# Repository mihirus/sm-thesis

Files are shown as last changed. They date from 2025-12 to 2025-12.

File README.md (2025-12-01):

```bash
├── cad
│   ├── cores
│   │   ├── etd44_core.SLDPRT
│   │   ├── etd49_core.SLDPRT
│   │   ├── etd54_core.SLDPRT
│   │   └── etd59_core.SLDPRT
│   ├── etd59_bobbin_integrated_secondary.SLDPRT
│   ├── etd59_shunt_AB.SLDPRT
│   ├── inverter_sink_v2_vertical.SLDPRT
│   └── leakage-transformer-assembly
│       ├── etd59_bobbin_integrated_v7.SLDPRT
│       ├── etd59_core.SLDPRT
│       ├── ETD59-integrated-base-raised-nov21.SLDPRT
│       ├── ETD59-integrated-bottom-raised-0.8mm-dec9.SLDPRT
│       ├── ETD59-integrated-top-raised-0.8mm-dec9.SLDPRT
│       ├── etd59-withsinks-raised-dec9.SLDASM
│       ├── secondary-placeholder.SLDPRT
│       ├── shunt-heat-sink.SLDPRT
│       └── shunt-heat-spreader.SLDPRT
├── optimization
│   ├── opt_baseline.py
│   ├── opt_heatsink.py
│   └── opt_integrated.py
├── pcb
│   ├── custom_assets (collapsed)
│   ├── inverter
│   │   ├── half_bridge.kicad_sch
│   │   ├── inverter.kicad_pcb
│   │   ├── inverter.kicad_prl
│   │   ├── inverter.kicad_pro
│   │   ├── inverter.kicad_sch
│   │   ├── inverter.pdf
│   │   ├── inverter.round-tracks-config
│   │   ├── inverter.step
│   │   └── outputs
│   │       ├── inverter-B_Cu.pdf
│   │       ├── inverter-F_Cu.pdf
│   │       ├── inverter-In1_Cu.pdf
│   │       └── inverter-In2_Cu.pdf
│   ├── multiplier-slu15mg-2p
│   │   ├── full_wave_cell-.kicad_sch
│   │   ├── full_wave_cell.kicad_sch
│   │   ├── multiplier-slu15mg.kicad_pcb
│   │   ├── multiplier-slu15mg.kicad_prl
│   │   ├── multiplier-slu15mg.kicad_pro
│   │   ├── multiplier-slu15mg.kicad_sch
│   │   ├── multiplier-slu15mg.step
│   │   └── outputs
│   │       ├── multiplier-slu15mg-B_Cu.pdf
│   │       ├── multiplier-slu15mg-Edge_Cuts.pdf
│   │       └── multiplier-slu15mg-F_Cu.pdf
│   └── tank-caps
│       ├── tank-caps.kicad_pcb
│       ├── tank-caps.kicad_prl
│       ├── tank-caps.kicad_pro
│       ├── tank-caps.kicad_sch
│       └── tank-caps.step
├── README.md
└── simulation
    ├── electromagnetic
    │   └── horizontal-interleaved-shunt-kenneth-muhammad.aedt
    └── thermal
        ├── etd59_core.aedt
        ├── inverter_heatsink_v2_vertical.aedt
        ├── thermal_horizontal_winding_cross_section_with_air.aedt
        └── thermal_horizontal_winding_cross_section_with_compound.aedt
```

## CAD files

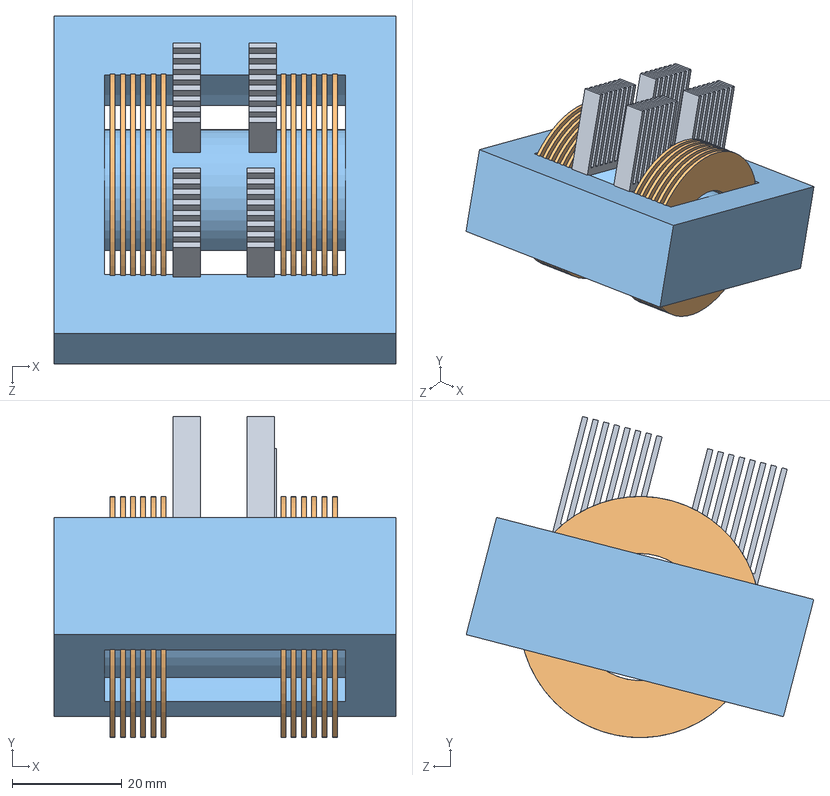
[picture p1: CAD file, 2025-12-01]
cad/leakage-transformer-assembly/etd59-withsinks-raised-dec9.SLDASM
62.4 x 58.6 x 63.4 mm
etd59_core
secondary-placeholder x 12
shunt-heat-sink x 4

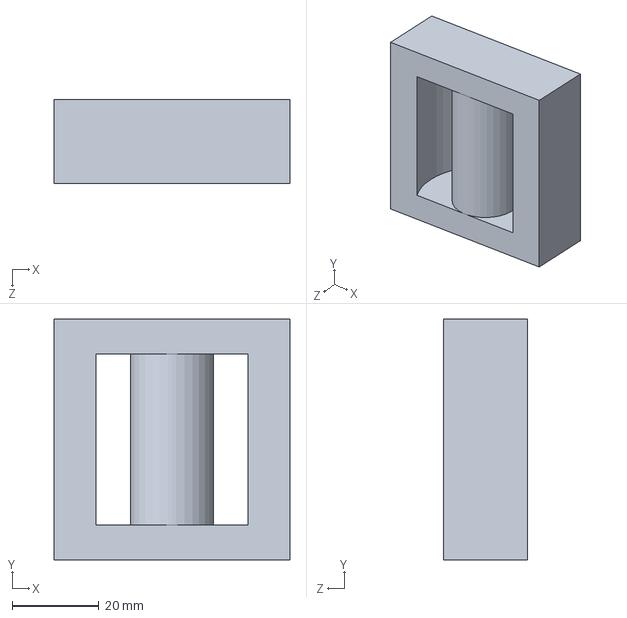
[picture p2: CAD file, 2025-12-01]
cad/cores/etd54_core.SLDPRT
54.5 x 55.6 x 19.3 mm

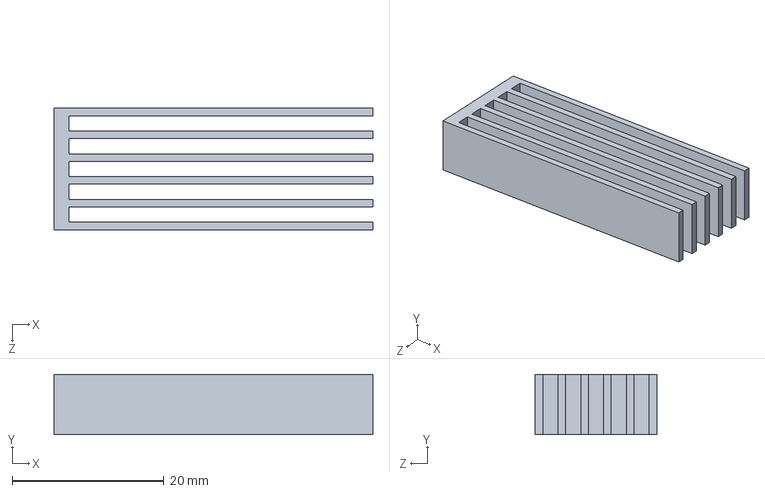
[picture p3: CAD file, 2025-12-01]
cad/inverter_sink_v2_vertical.SLDPRT
42.0 x 7.94 x 16.0 mm

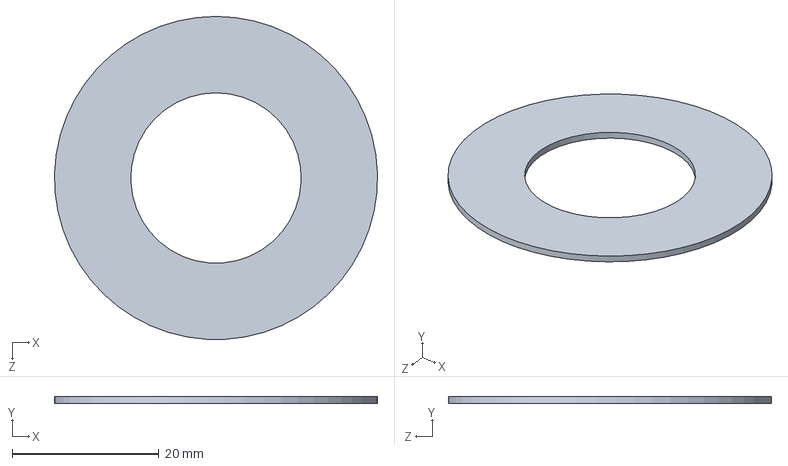
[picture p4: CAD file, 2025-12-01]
cad/leakage-transformer-assembly/secondary-placeholder.SLDPRT
44.0 x 0.9 x 44.0 mm

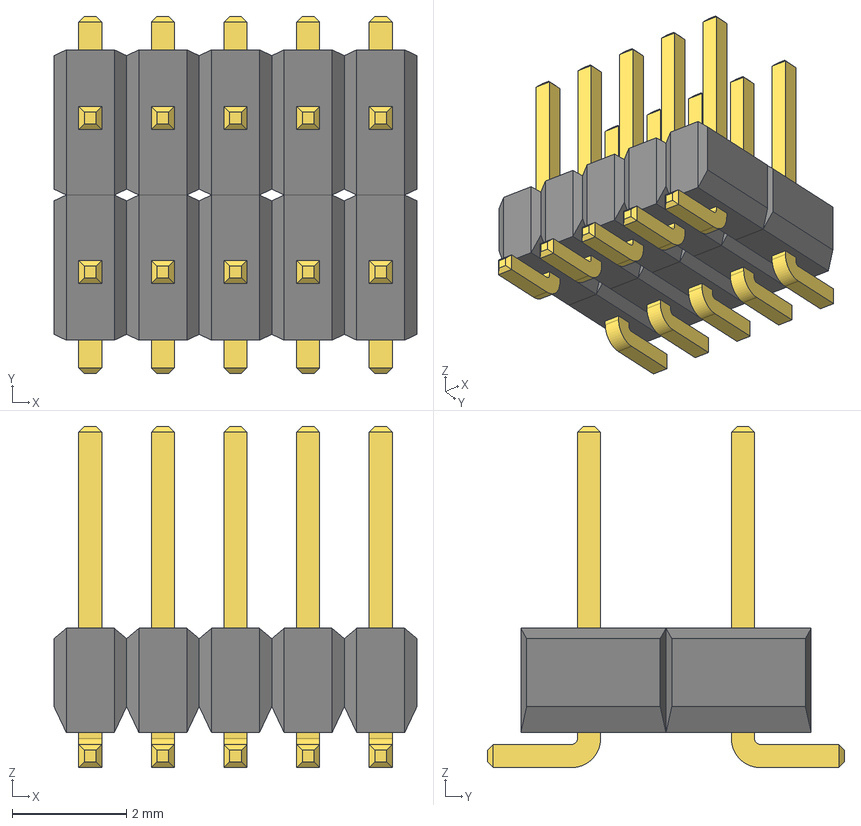
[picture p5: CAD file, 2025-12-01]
pcb/custom_assets/CON10_2X5_DUK_FTSH_SAI.step
6.35 x 6.25 x 5.97 mm

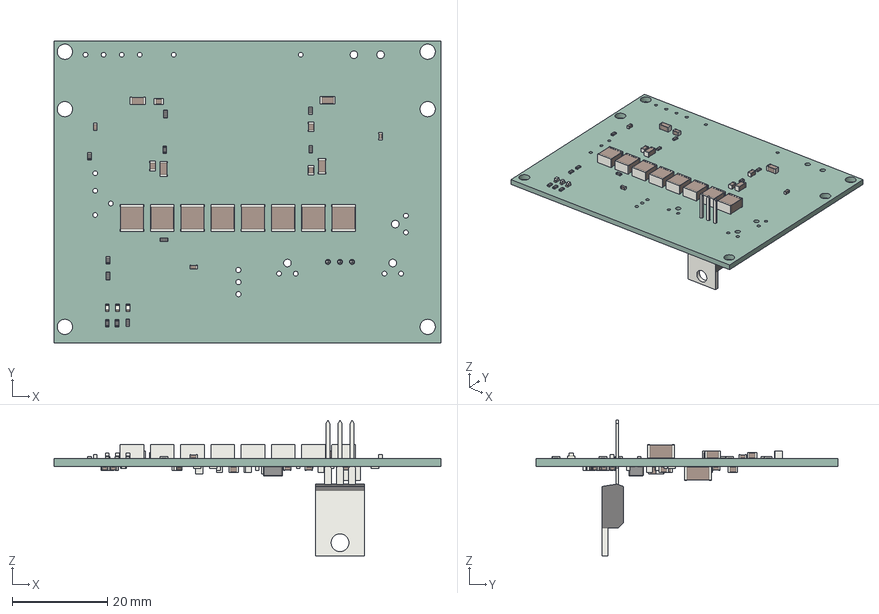
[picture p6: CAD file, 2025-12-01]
pcb/inverter/inverter.step
81.3 x 63.5 x 28.5 mm
R_0603_1608Metric x 19
C_1206_3216Metric x 6
LED_0603_1608Metric x 3
C_2220_5650Metric x 9
C_0603_1608Metric x 14
C_0805_2012Metric x 9
TO-220-3_Vertical
R_0805_2012Metric
L_Wuerth_MAPI_4020
inverter PCB

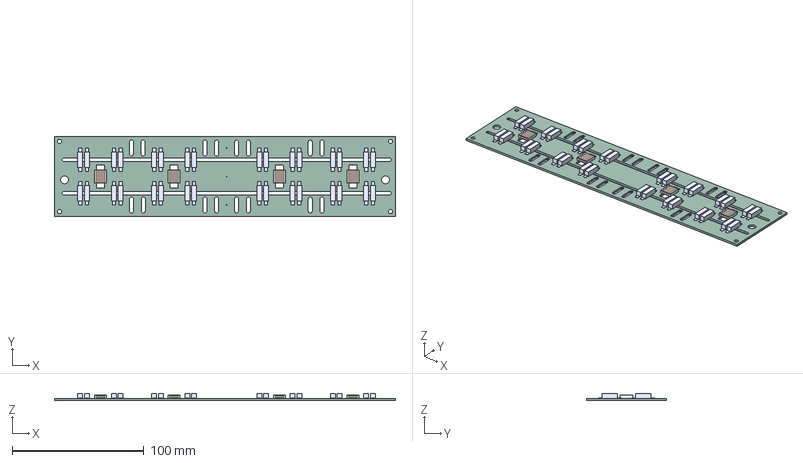
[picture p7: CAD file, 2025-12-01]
pcb/multiplier-slu15mg-2p/multiplier-slu15mg.step
259.1 x 61.0 x 5.45 mm
slu15mg x 32
C_3640_9110Metric x 4
multiplier-slu15mg PCB

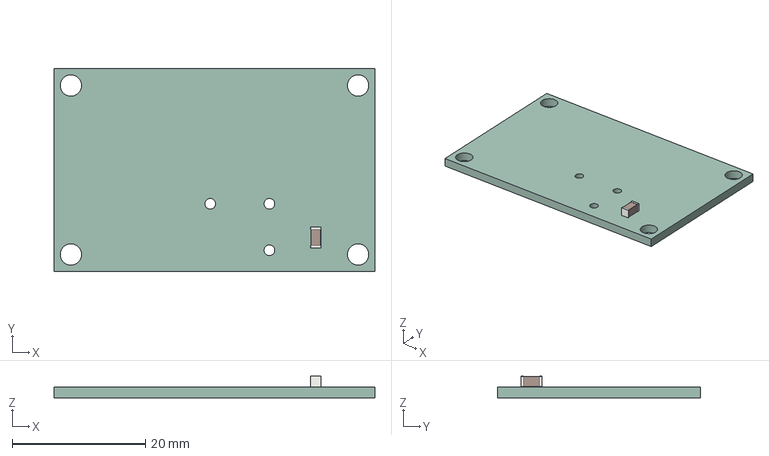
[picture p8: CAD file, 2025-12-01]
pcb/tank-caps/tank-caps.step
48.3 x 30.5 x 3.25 mm
C_1206_3216Metric
tank-caps PCB

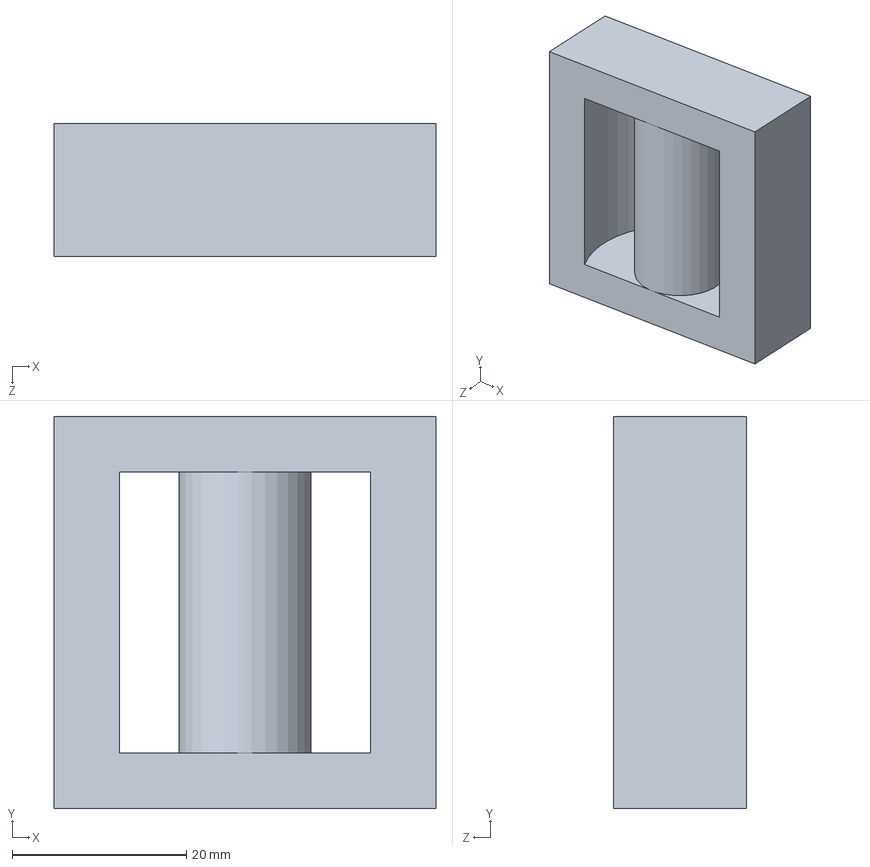
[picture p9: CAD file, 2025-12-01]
cad/cores/etd44_core.SLDPRT
43.8 x 45.0 x 15.2 mm

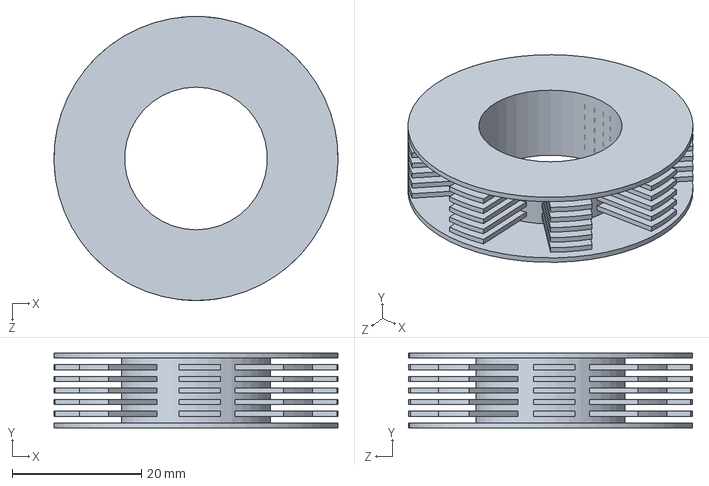
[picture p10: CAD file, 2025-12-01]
cad/etd59_bobbin_integrated_secondary.SLDPRT
44.0 x 11.6 x 44.0 mm

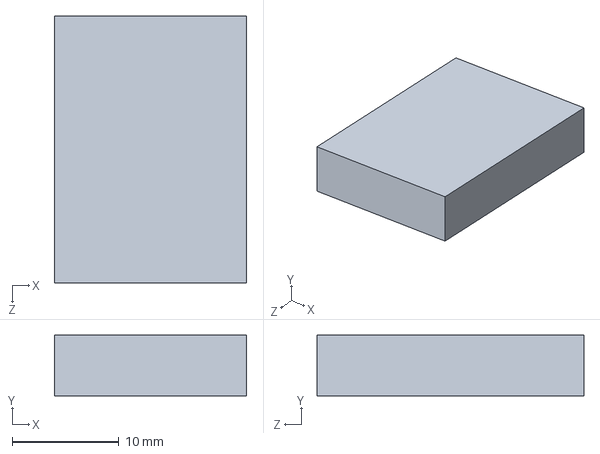
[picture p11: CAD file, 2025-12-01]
cad/leakage-transformer-assembly/shunt-heat-spreader.SLDPRT
18.0 x 5.67 x 25.0 mm

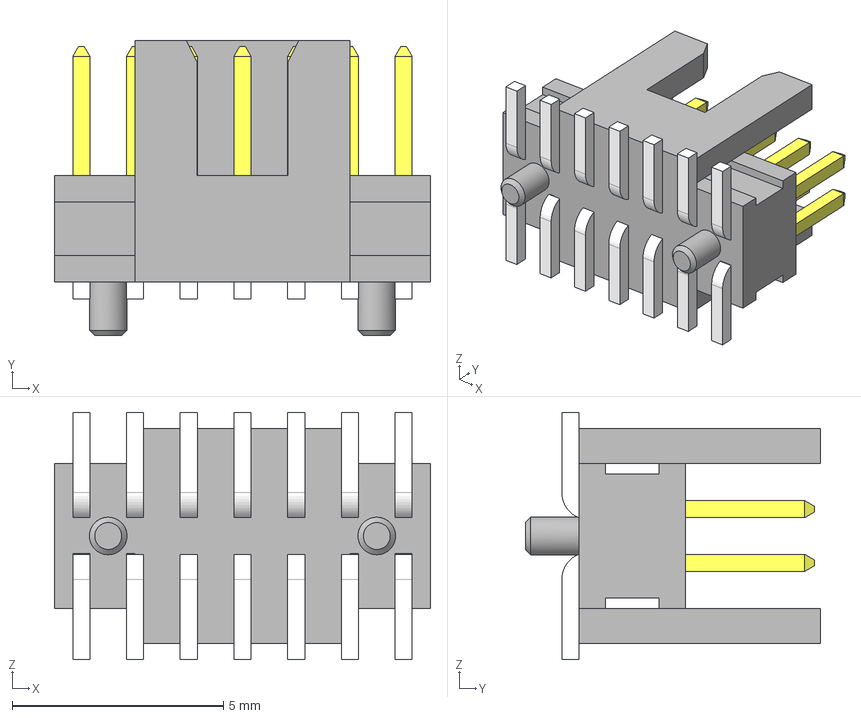
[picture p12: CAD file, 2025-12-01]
pcb/custom_assets/FTSH-107-01-L-DV-K-A.step
8.89 x 6.98 x 5.84 mm
FTSH-107-01-L-DV-K-A_pins2
FTSH-107-01-L-DV-K-A_pins1
FTSH-107-01-L-DV-K-A_body

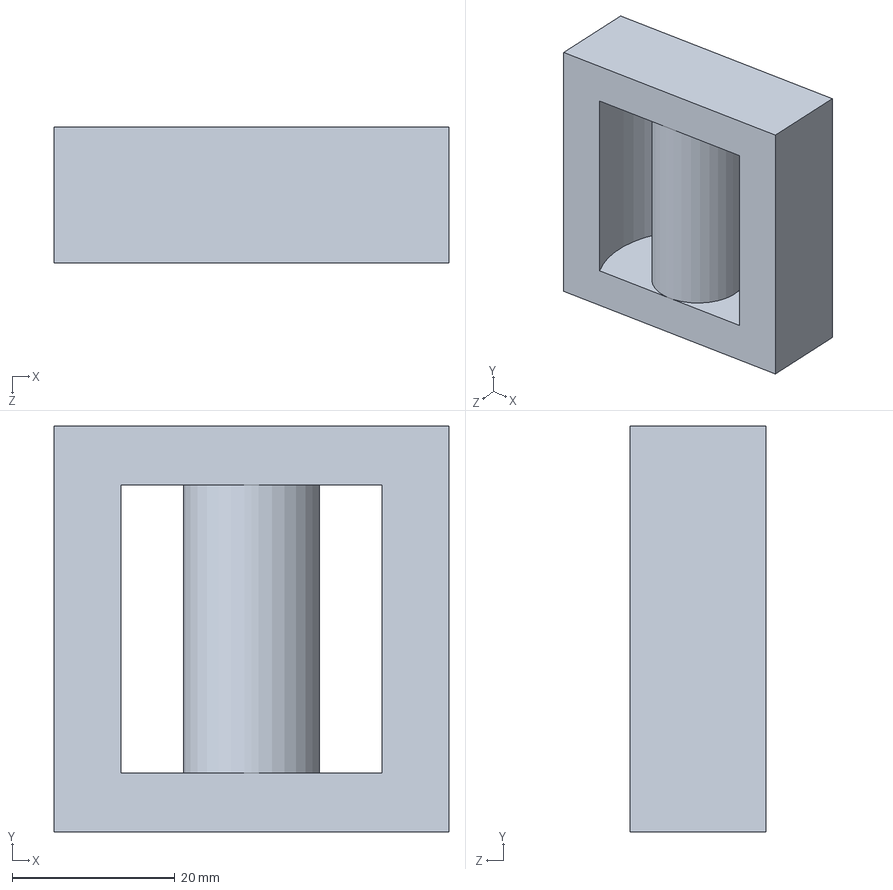
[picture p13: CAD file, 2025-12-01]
cad/cores/etd49_core.SLDPRT
48.5 x 49.8 x 16.7 mm

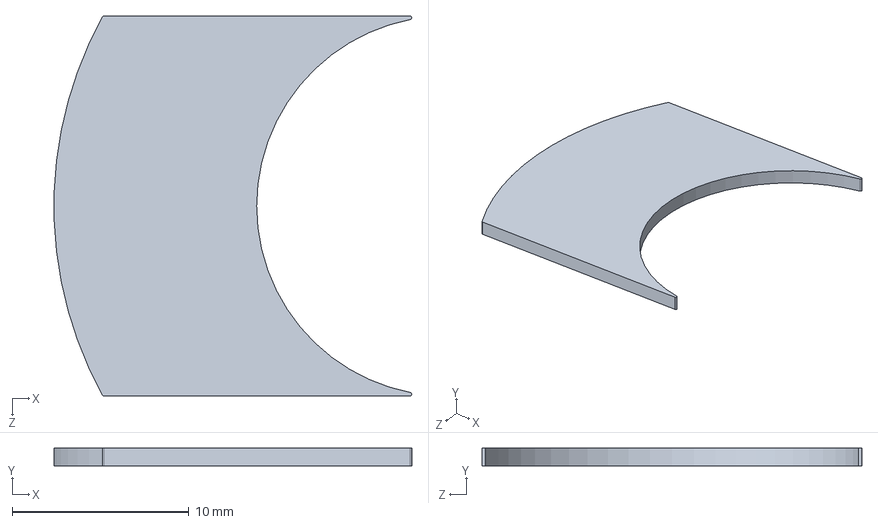
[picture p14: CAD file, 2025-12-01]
cad/etd59_shunt_AB.SLDPRT
20.3 x 1.00 x 21.5 mm

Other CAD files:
cad/leakage-transformer-assembly/shunt-heat-sink.SLDPRT
pcb/custom_assets/RM-0505S_P.step
cad/cores/etd59_core.SLDPRT
cad/leakage-transformer-assembly/etd59_core.SLDPRT
cad/leakage-transformer-assembly/ETD59-integrated-base-raised-nov21.SLDPRT
cad/leakage-transformer-assembly/ETD59-integrated-bottom-raised-0.8mm-dec9.SLDPRT
cad/leakage-transformer-assembly/ETD59-integrated-top-raised-0.8mm-dec9.SLDPRT
cad/leakage-transformer-assembly/etd59_bobbin_integrated_v7.SLDPRT
pcb/custom_assets/GS66508B-MR.step
pcb/custom_assets/GS66516T-MR.step

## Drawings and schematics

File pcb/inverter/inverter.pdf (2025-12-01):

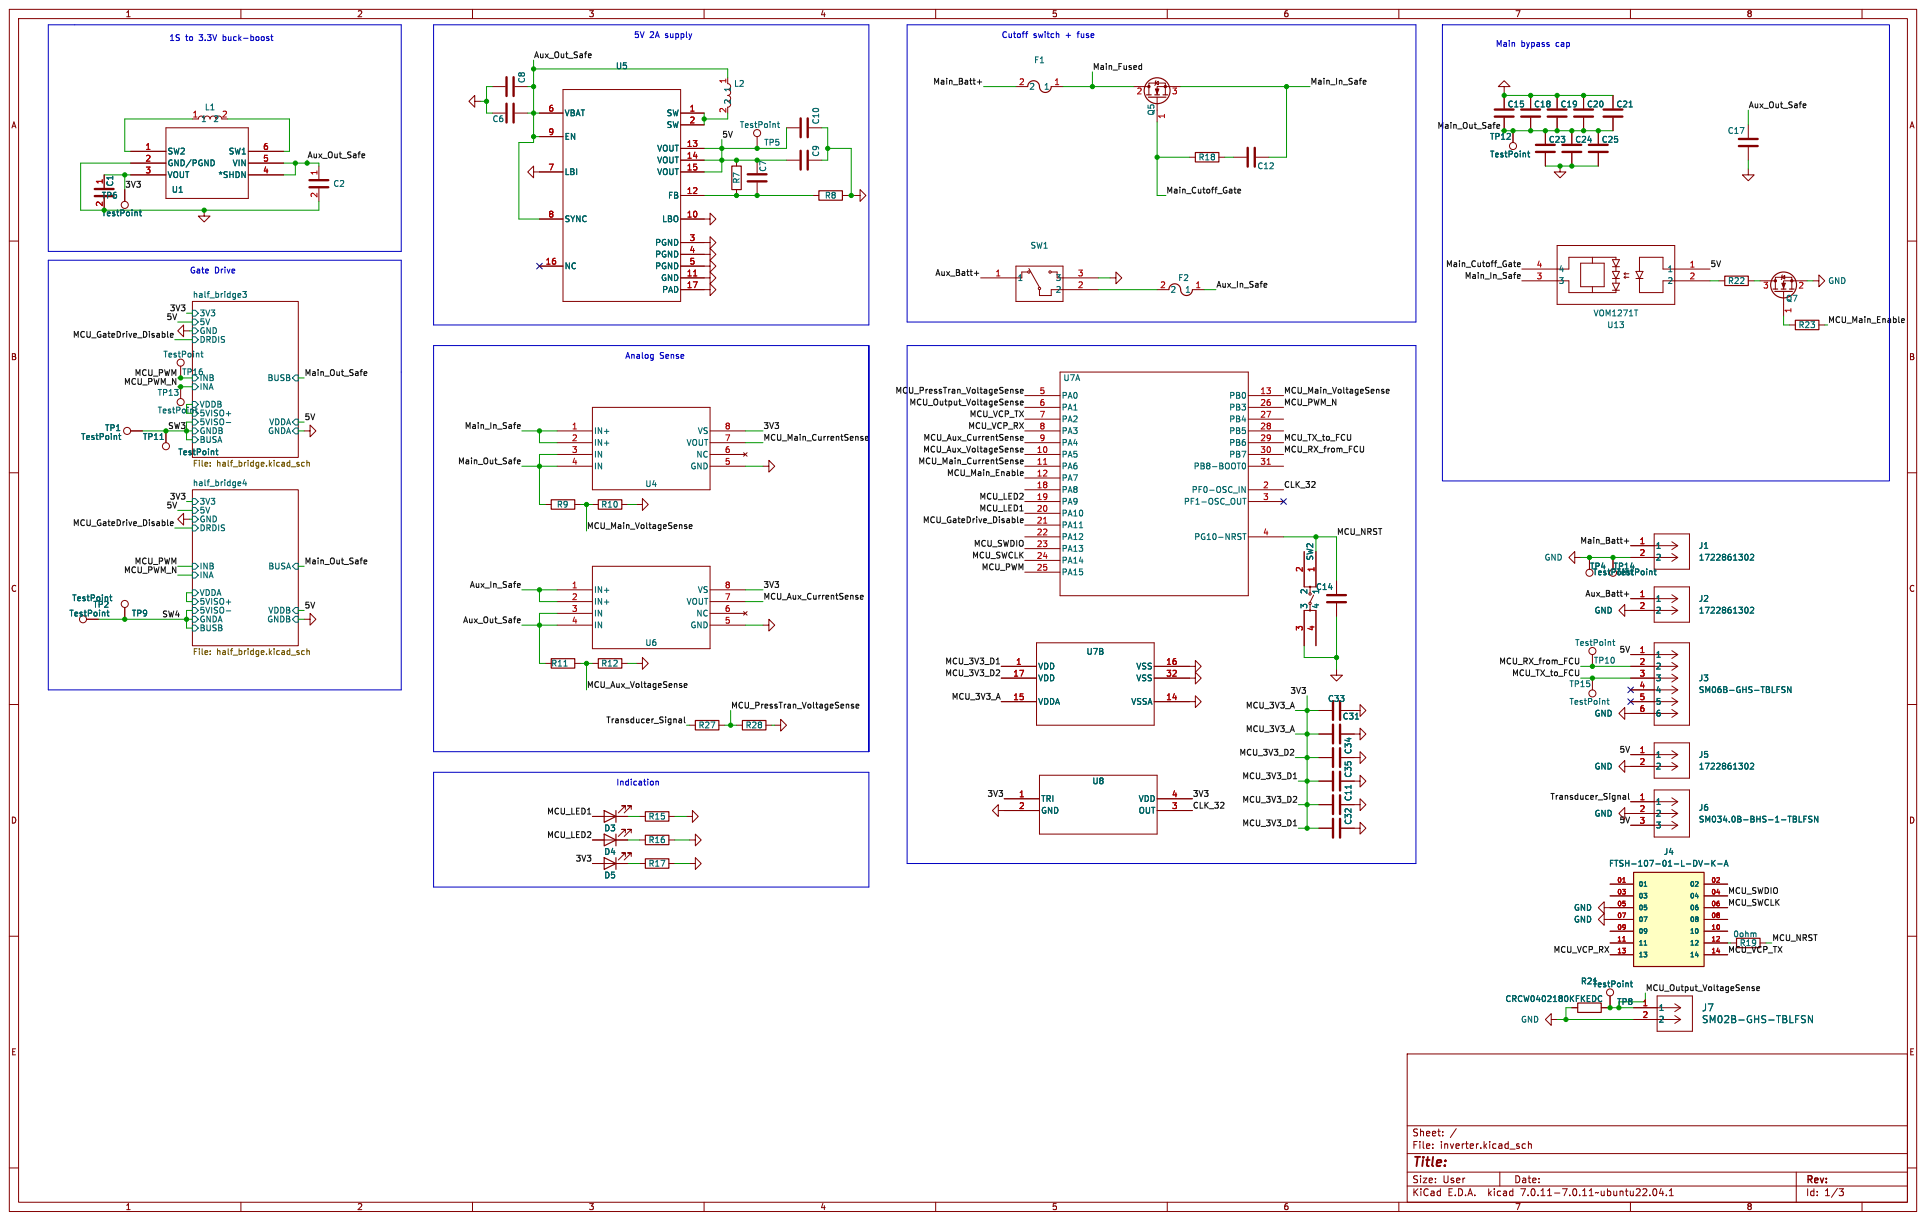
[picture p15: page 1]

1 2 C2 C8 C6 TP2 TestPoint TP13 TestPoint SW2 1 GND/PGND 2 VOUT 3

Id: 1/3 Title: File: inverter.kicad_sch Sheet: /

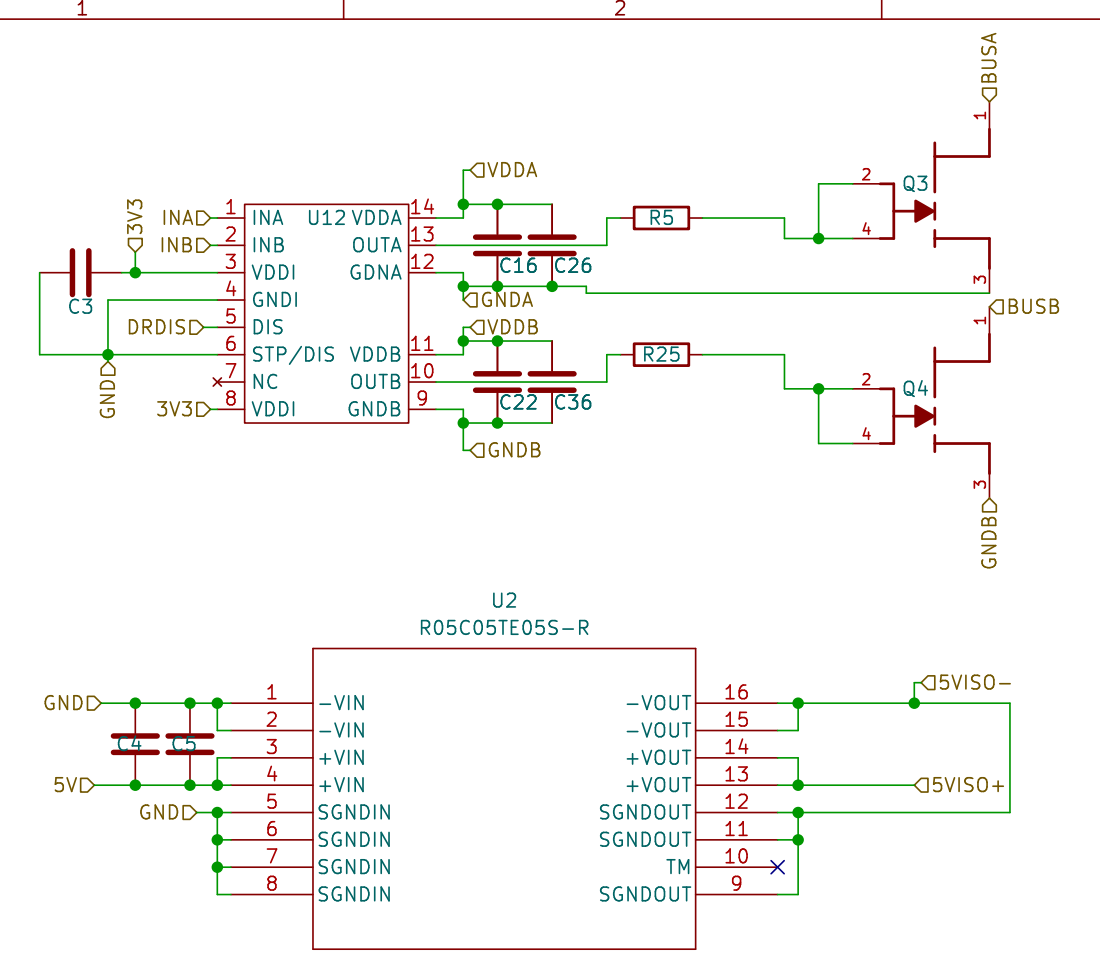
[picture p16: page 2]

Id: 3/3 Title: File: half_bridge.kicad_sch Sheet: /half_bridge4/

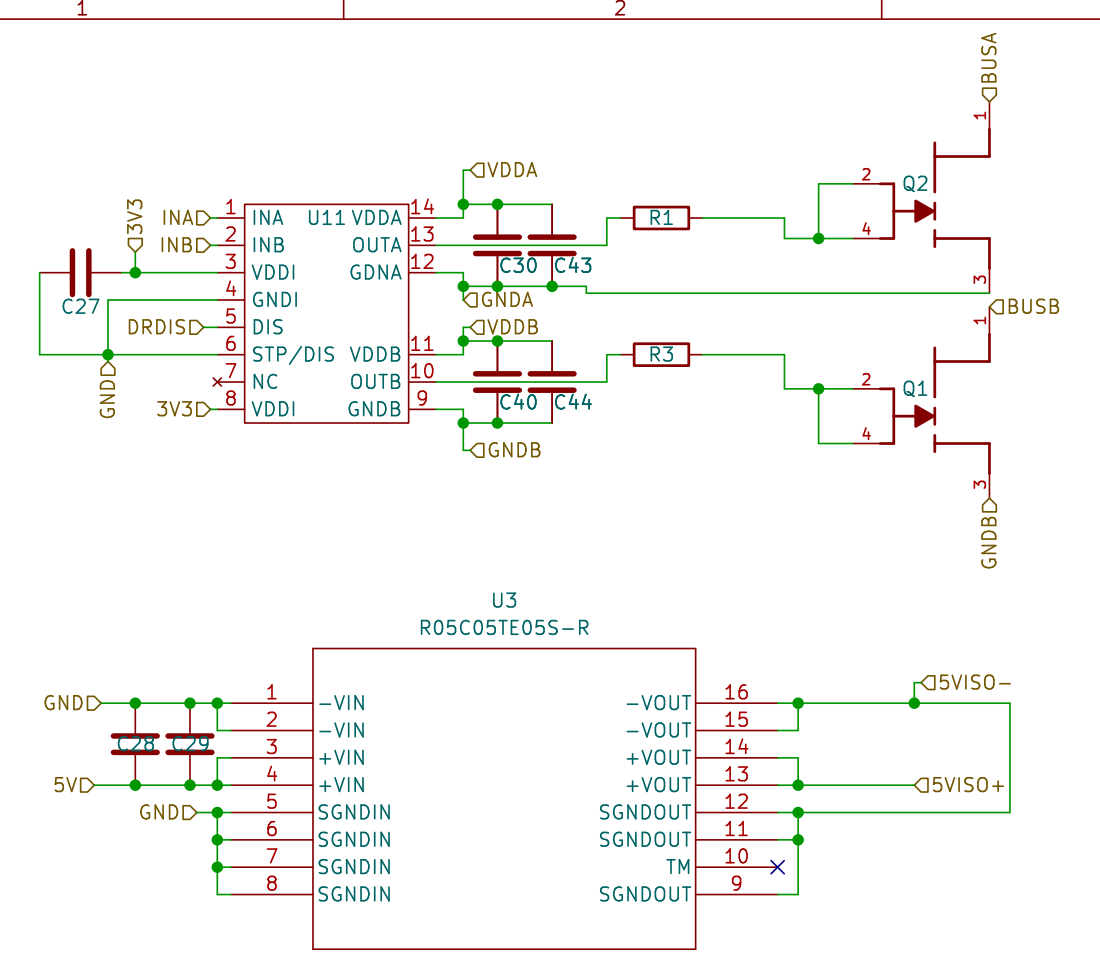
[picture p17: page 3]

Id: 4/3 Title: File: half_bridge.kicad_sch Sheet: /half_bridge3/

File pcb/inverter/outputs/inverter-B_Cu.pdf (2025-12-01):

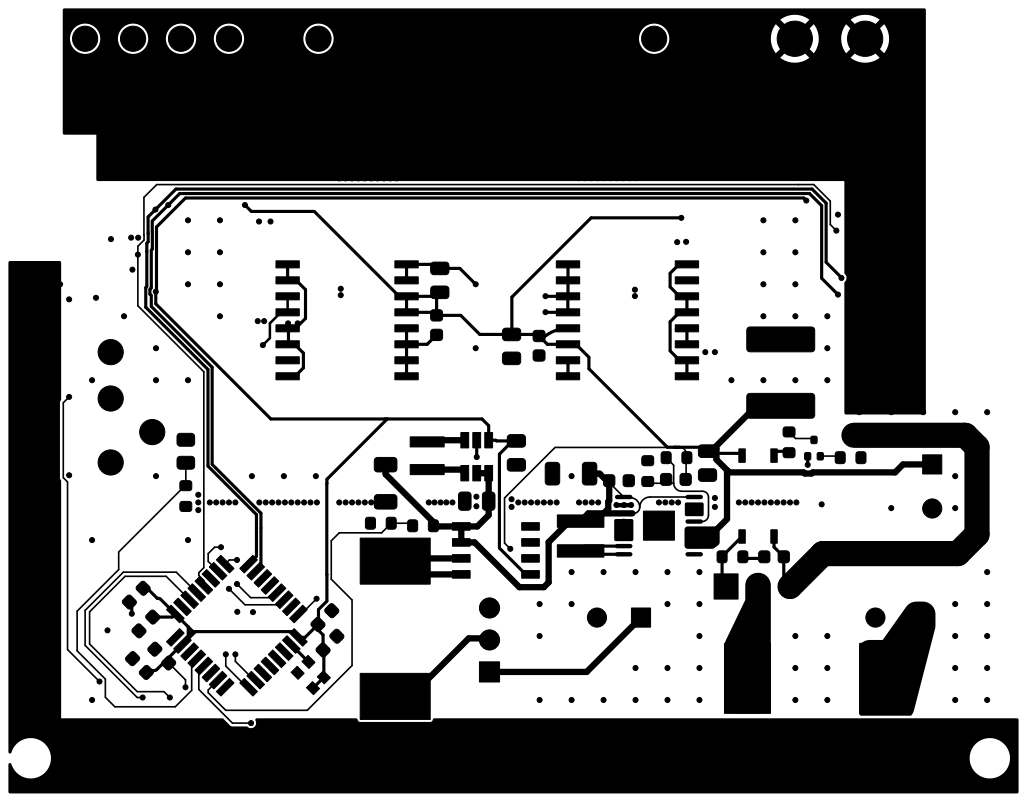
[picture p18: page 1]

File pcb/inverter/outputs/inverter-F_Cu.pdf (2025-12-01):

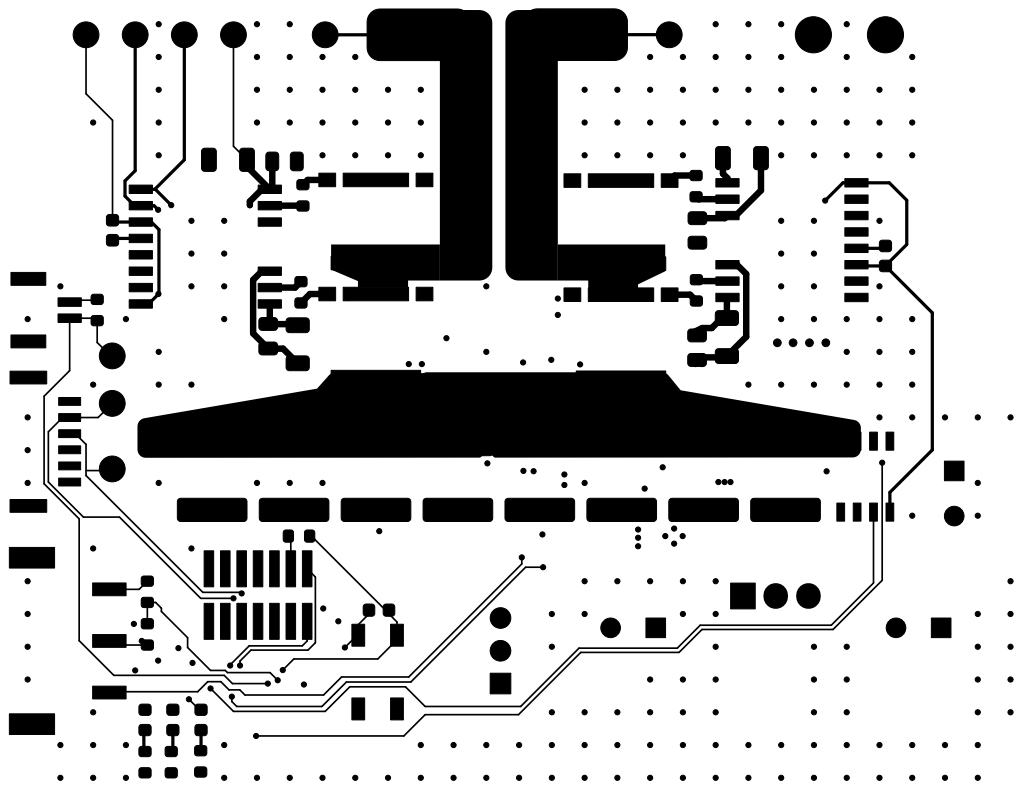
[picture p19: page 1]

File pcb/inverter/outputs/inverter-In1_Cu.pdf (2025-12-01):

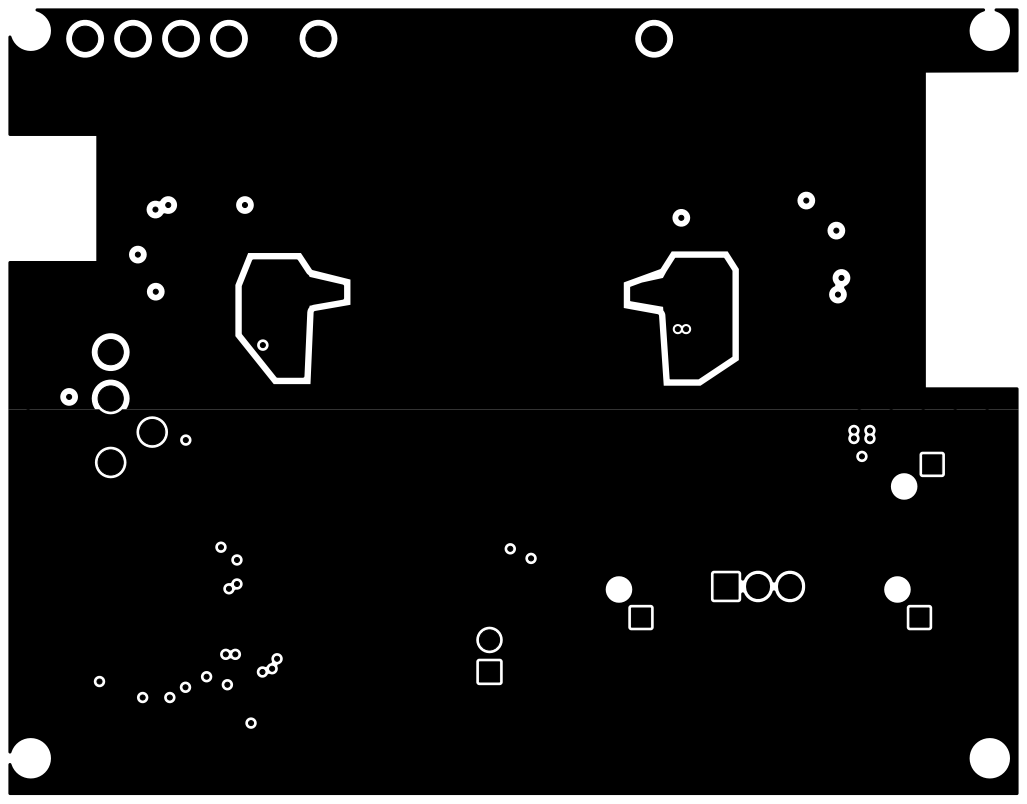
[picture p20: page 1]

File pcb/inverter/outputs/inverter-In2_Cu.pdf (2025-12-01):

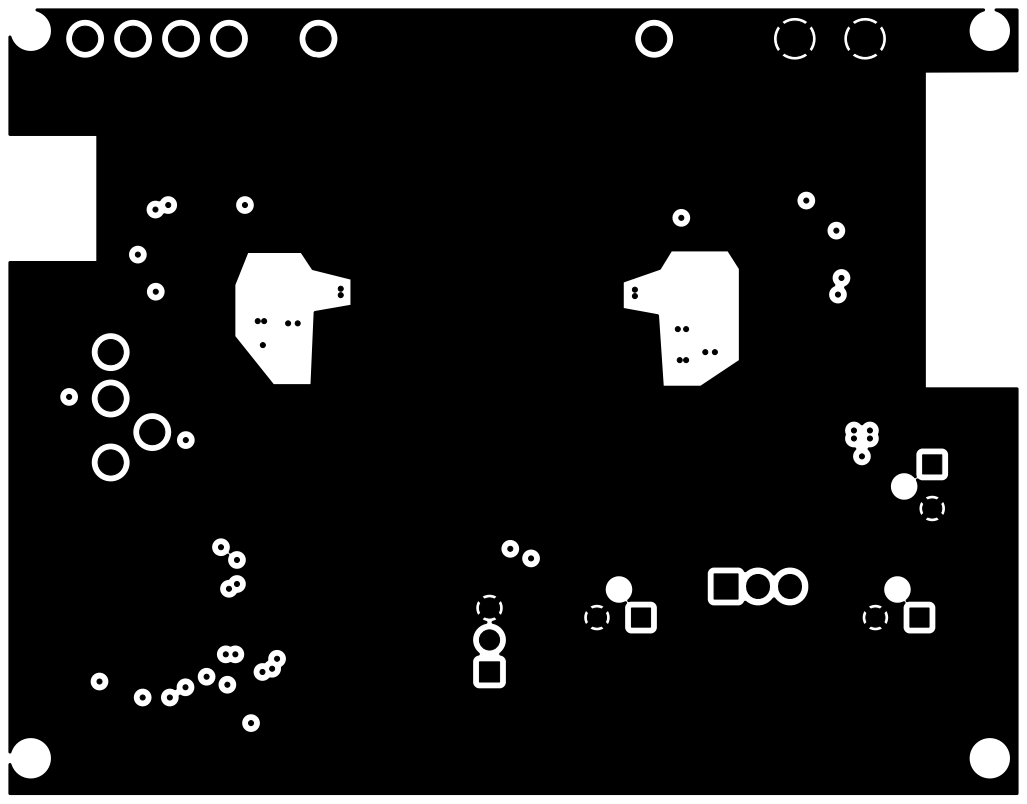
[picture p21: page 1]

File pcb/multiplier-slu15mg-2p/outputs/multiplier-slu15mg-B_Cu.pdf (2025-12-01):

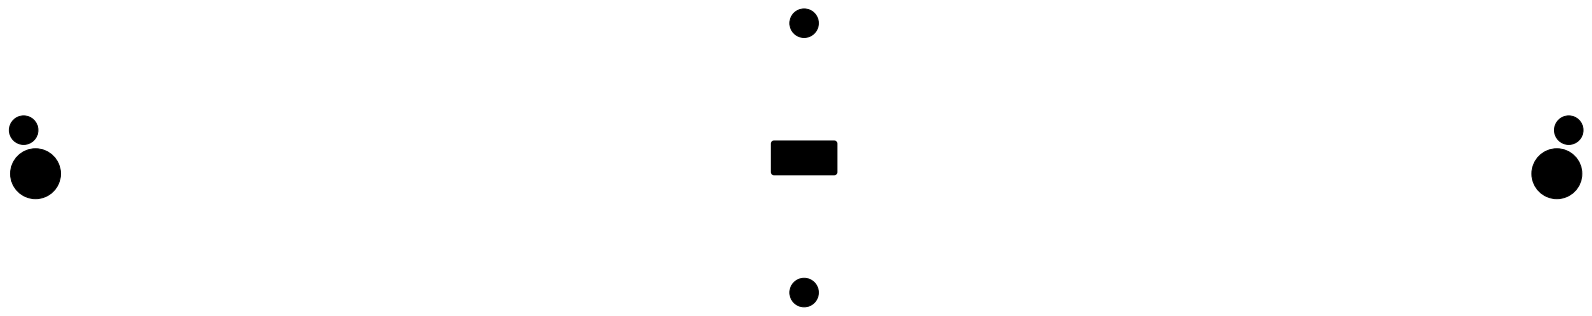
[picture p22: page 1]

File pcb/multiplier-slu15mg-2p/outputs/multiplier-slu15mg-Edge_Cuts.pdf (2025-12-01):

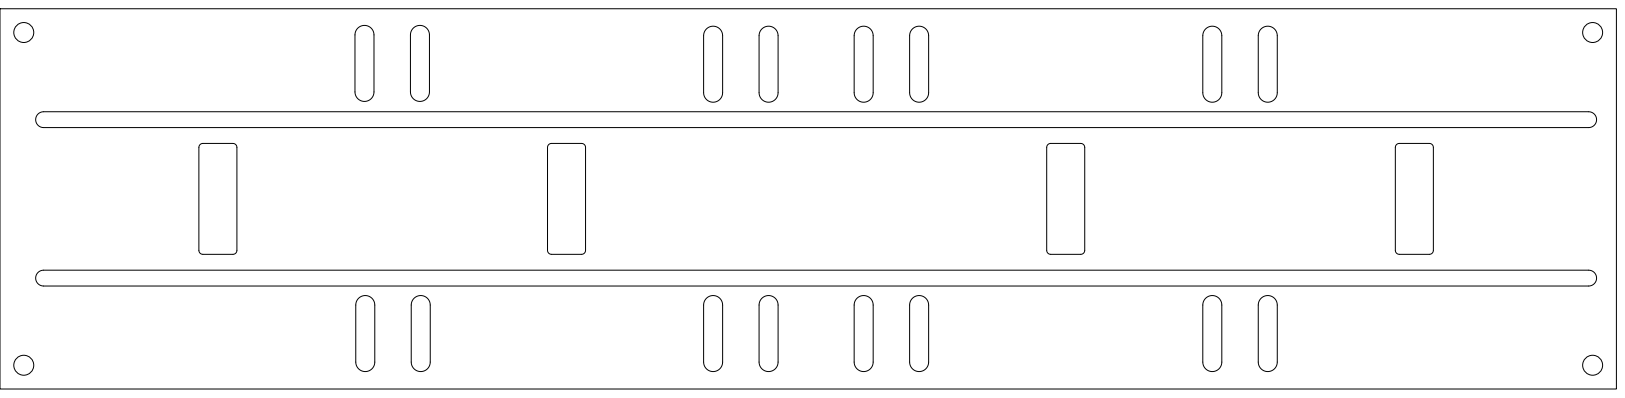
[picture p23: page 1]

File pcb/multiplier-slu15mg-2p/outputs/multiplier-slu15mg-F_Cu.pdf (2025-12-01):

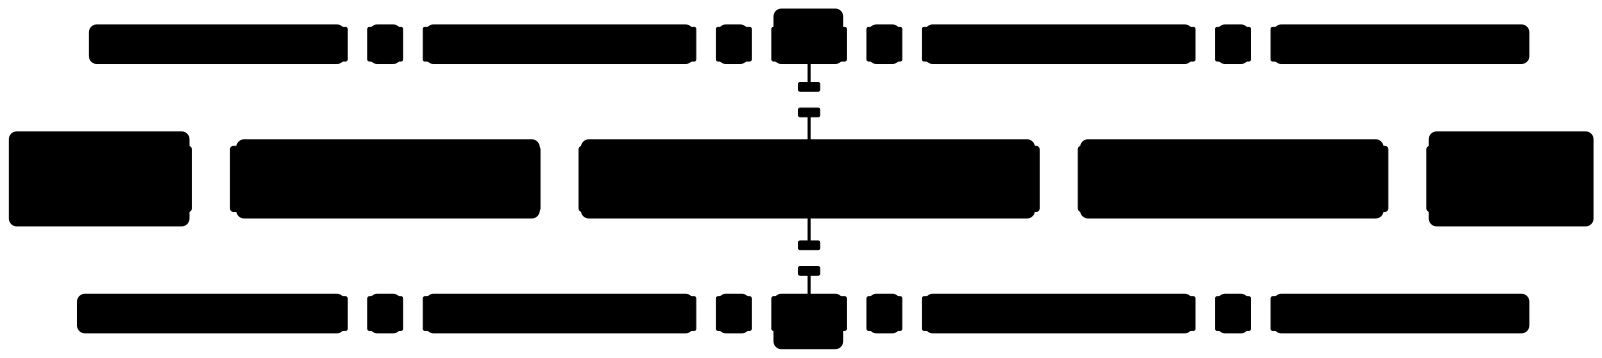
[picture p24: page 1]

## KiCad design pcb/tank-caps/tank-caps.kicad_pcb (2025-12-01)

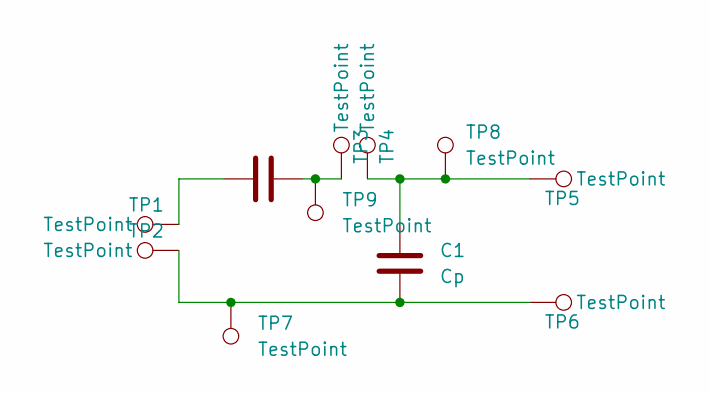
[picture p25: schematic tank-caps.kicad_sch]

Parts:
C1: Cp; C_1206_3216Metric
C2: Cs; C_2220_5750Metric
TP1, TP2, TP3, TP4, TP5, TP6: TestPoint; output_pad_4x8mm
TP7, TP8, TP9: TestPoint; TestPoint_Keystone_5005-5009_Compact

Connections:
unnamed: C1.1, TP4.1, TP5.1, TP8.1
unnamed: C1.2, TP2.1, TP6.1, TP7.1
unnamed: C2.1, TP1.1
unnamed: C2.2, TP3.1, TP9.1

Board: 2 copper layers, 11 parts (2 on the bottom side), 4 nets, no tracks yet.

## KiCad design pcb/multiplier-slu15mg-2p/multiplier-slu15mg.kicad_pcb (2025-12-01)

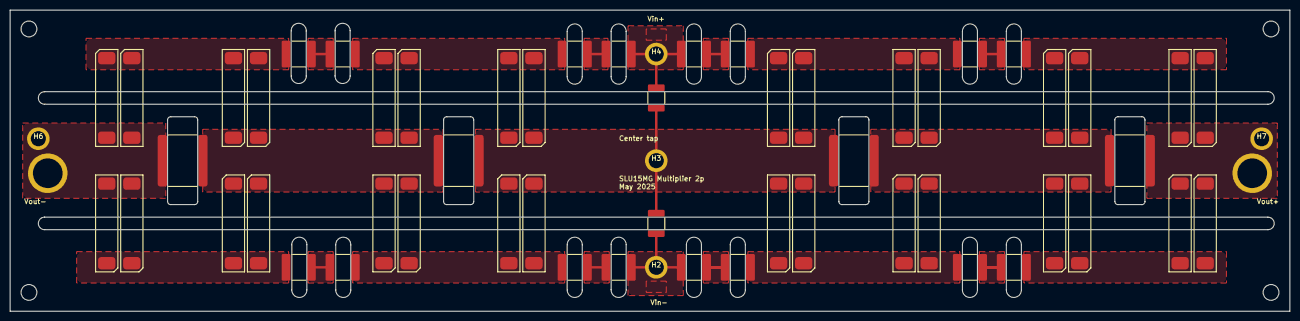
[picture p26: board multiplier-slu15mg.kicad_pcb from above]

Board: 2 copper layers, 259.1 x 61.0 mm, 61 parts (0 on the bottom side), 23 nets.

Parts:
C1, C2, C3, C4, C6, C7, C8, C9, C11, C12, C13, C14, C16, C17, C18, C19: C; C_2220_5750Metric
C5, C10, C15, C20: C; C_3640_9110Metric_HV
C21, C22: C; C_1812_4532Metric
D1, D2, D3, D4, D5, D6, D7, D8, D9, D10, D11, D12, D13, D14, D15, D16, D17, D18, D19, D20, D21, D22, D23, D24, D25, D26, D27, D28, D29, D30, D31, D32: D; slu15mg
H1, H2, H3, H4, H5: MountingHole_Pad; hv_clip_pth_6mm
H6, H7: MountingHole_Pad; output_pad_4mm

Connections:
/full_wave_cell1/O+: C8.2, C16.1, D5.2 (A), D7.1 (K), D25.1 (K), D29.2 (A)
/full_wave_cell1/O-: C9.2, C17.1, D6.2 (A), D8.1 (K), D26.1 (K), D30.2 (A)
/full_wave_cell1/O=: C10.2, C20.1, D7.2 (A), D8.2 (A), D13.1 (K), D14.1 (K), D25.2 (A), D26.2 (A), D31.1 (K), D32.1 (K)
/full_wave_cell2/O+: C13.2, D9.1 (K), D11.2 (A), D18.1 (K), D24.2 (A)
/full_wave_cell2/O-: C14.2, D10.1 (K), D12.2 (A), D20.1 (K), D22.2 (A)
/full_wave_cell2/O=: C15.2, D11.1 (K), D12.1 (K), D22.1 (K), D24.1 (K), H5.1, H7.1
/full_wave_cell3/O+: C18.2, D13.2 (A), D15.1 (K), D27.1 (K), D31.2 (A)
/full_wave_cell3/O-: C19.2, D14.2 (A), D16.1 (K), D28.1 (K), D32.2 (A)
/full_wave_cell3/O=: C20.2, D15.2 (A), D16.2 (A), D27.2 (A), D28.2 (A), H1.1, H6.1
/full_wave_cell/I+: C1.1, C7.1, C21.2, H4.1
/full_wave_cell/I-: C2.1, C6.1, C22.2, H2.1
/full_wave_cell/I=: C5.1, C10.1, C21.1, C22.1, D1.2 (A), D2.2 (A), D5.1 (K), D6.1 (K), D17.2 (A), D19.2 (A), D29.1 (K), D30.1 (K), H3.1
/full_wave_cell/O+: C3.2, C11.1, D1.1 (K), D3.2 (A), D17.1 (K), D23.2 (A)
/full_wave_cell/O-: C4.2, C12.1, D2.1 (K), D4.2 (A), D19.1 (K), D21.2 (A)
/full_wave_cell/O=: C5.2, C15.1, D3.1 (K), D4.1 (K), D9.2 (A), D10.2 (A), D18.2 (A), D20.2 (A), D21.1 (K), D23.1 (K)
unnamed: C1.2, C3.1
unnamed: C2.2, C4.1
unnamed: C6.2, C8.1
unnamed: C7.2, C9.1
unnamed: C11.2, C13.1
unnamed: C12.2, C14.1
unnamed: C16.2, C18.1
unnamed: C17.2, C19.1

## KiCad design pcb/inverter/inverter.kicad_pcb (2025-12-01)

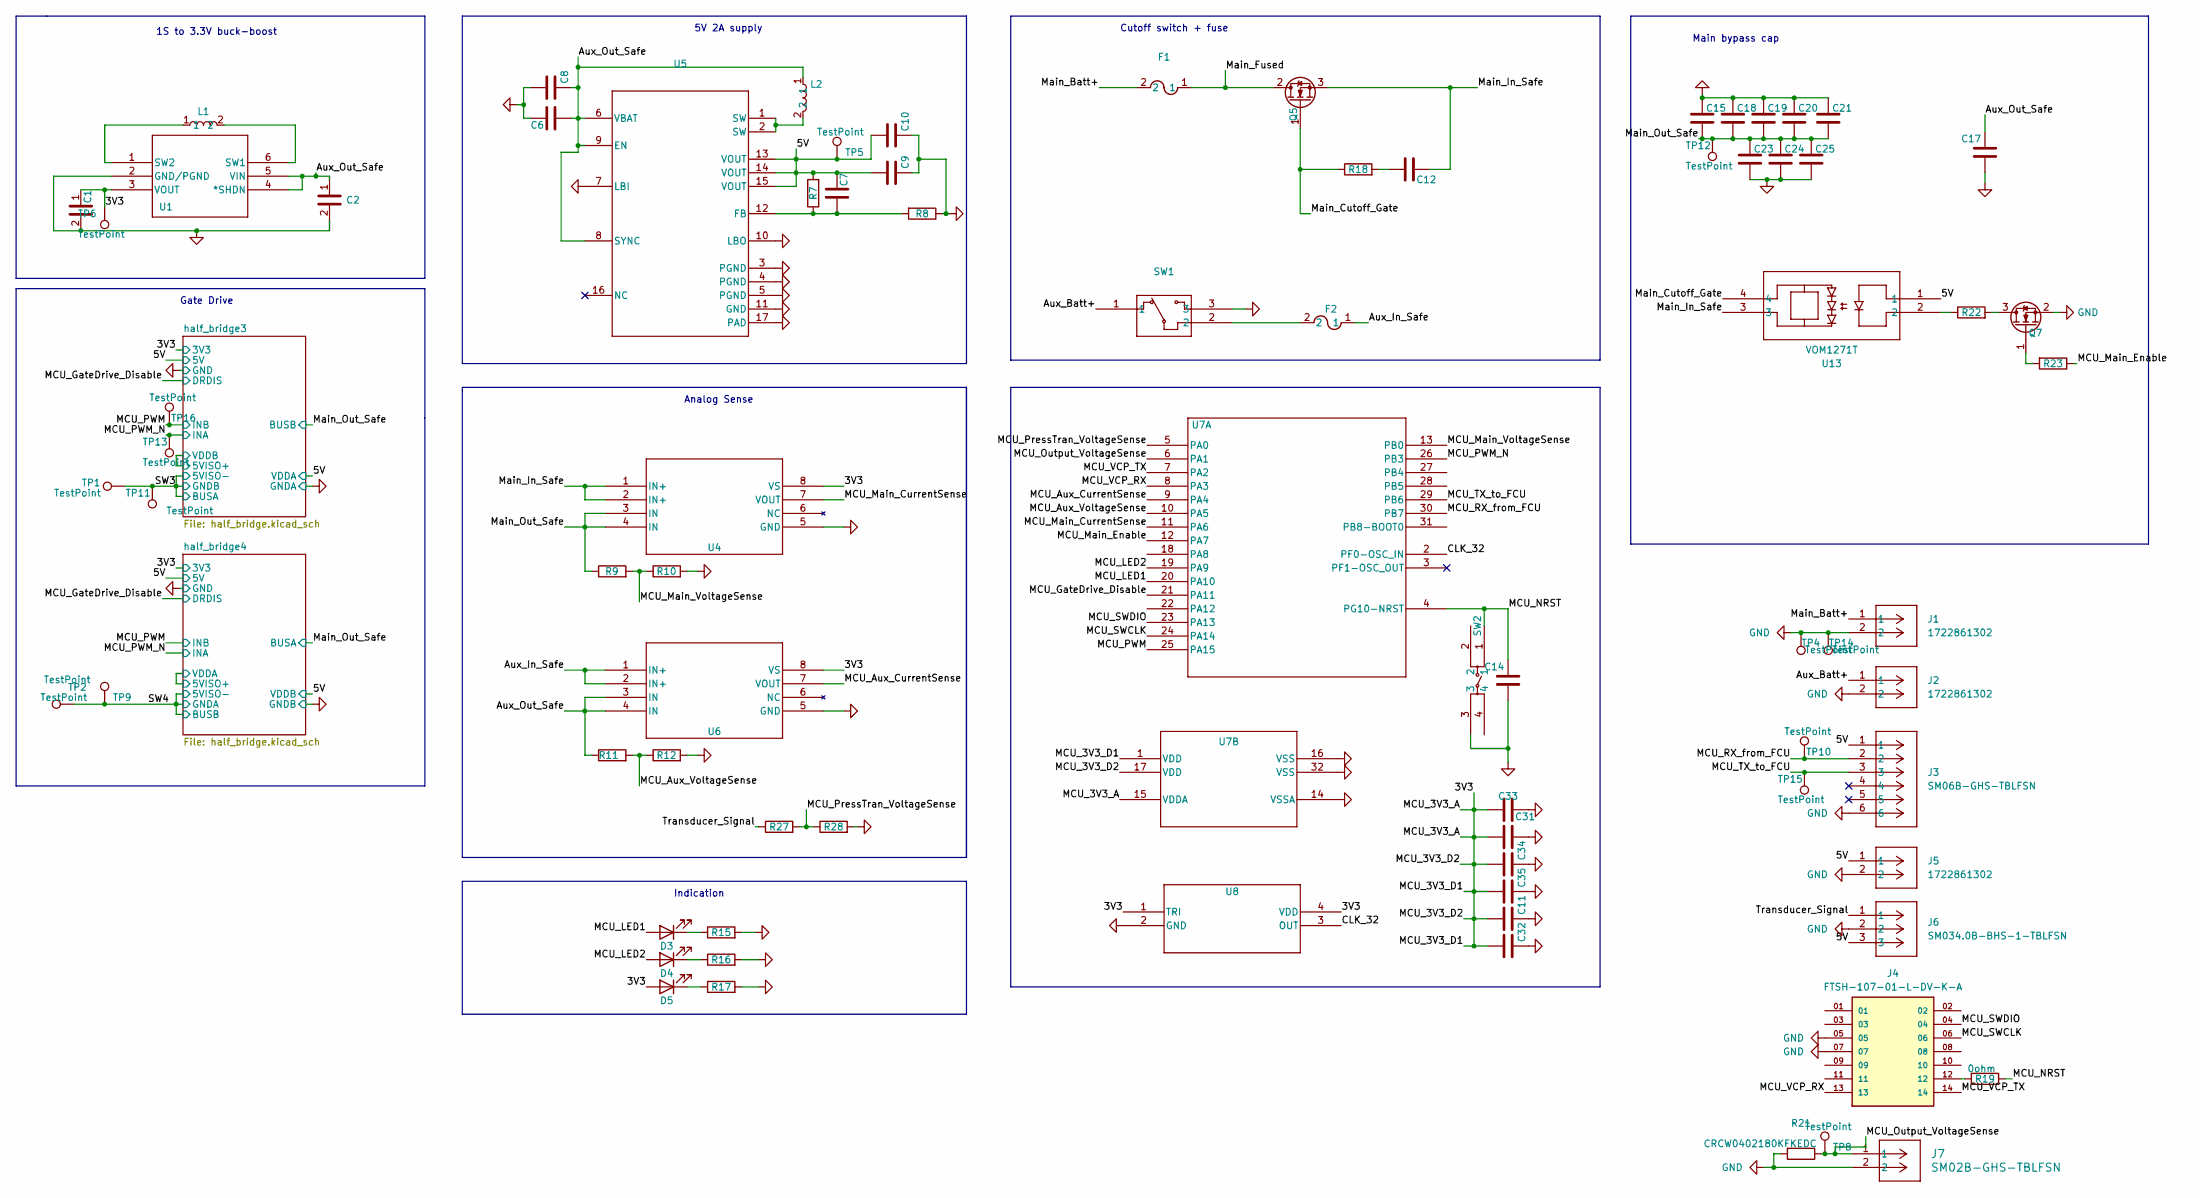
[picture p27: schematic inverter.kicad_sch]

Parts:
C1: GRT21BR61C226ME13K; C_0805_2012Metric
C2: CL21B475KOQVPNE; C_0805_2012Metric
C6: CGA5L3X5R1H106M160AB; C_1206_3216Metric
C7: KGQ05FCG1H100FH; C_0603_1608Metric
C8, C11, C14, C32: C1005X7R1H104K050BB; C_0603_1608Metric
C9: CKG57NX7R1V107M500JJ; C_2220_5650Metric_Pad1.97x5.40mm_HandSolder
C10: C2012X7R1H225K125AC; C_0805_2012Metric
C12: C; C_0603_1608Metric
C15, C18, C19, C20, C21, C23, C24, C25: 2220Y5000105KJTWS2; C_2220_5650Metric
C17: C3216X7R1E106K160AB; C_1206_3216Metric
C31: C1608X7R1V105K080AE; C_0603_1608Metric
C33: C1005X7R1H103K050BB; C_0603_1608Metric
C34, C35: GRM188Z71A475KE15J; C_0603_1608Metric
D3: QBLP601-R5; LED_0603_1608Metric
D4: QBLP601-AG15; LED_0603_1608Metric
D5: QBLP601-IB5; LED_0603_1608Metric
F1: TR-1350HV5-R; FUSE_1350HV_EAT
F2: TR-1350HV2-R; FUSE_1350HV_EAT
J1, J2, J5: 1722861302; CON_1722861302_MOL
J3: SM06B-GHS-TBLFSN; CONN_SM06B-GHS-TB_JST
J4: FTSH-107-01-L-DV-K-A; SAMTEC_FTSH-107-01-L-DV-K-A; PARTREV H; DigiKey_Part_Number FTSH-107-01-L-DV-K-A-ND
J6: SM034.0B-BHS-1-TBLFSN; CONN_SM034.0B-BHS-1-TB_JST
J7: SM02B-GHS-TBLFSN; CONN_SM02B-GHS-TBLFSN_JST
L1: LSXND3030QKT100MNG
L2: 74438357022; L_Wuerth_MAPI-4020
Q5: UF3C065030T3S; TO-220-3_Vertical
Q7: SSM3K35AFS; SOT-416
R7: RMCF0603FT1M62; R_0603_1608Metric
R8: CRCW0603180KFKEAHP; R_0603_1608Metric
R9: TNPV08051M00BEEA; R_0805_2012Metric
R10, R11, R12: MCT0603MD1002BP500; R_0603_1608Metric
R15: RK73H1JTTD3000F; R_0603_1608Metric
R16: RK73H1JTTD2800F; R_0603_1608Metric
R17: RK73H1JTTD82R0F; R_0603_1608Metric
R18: R; R_0603_1608Metric
R19: 0ohm; R_0603_1608Metric
R21: CRCW0402180KFKEDC; R_0603_1608Metric
R22: RK73H1ETTP3600F; R_0603_1608Metric
R23: RK73H1ETTP1001F; R_0603_1608Metric
R27: RK73H1ETTP2203F; R_0603_1608Metric
R28: RMCF0603FT280K; R_0603_1608Metric
SW1: 500ASSP3M2QE; 500ASSP3M2QE_EWI
SW2: PTS 647 SN50 SMTR2 LFS
TP1, TP2: TestPoint; output_pad_4x8mm
TP4, TP14: TestPoint; TestPoint_Keystone_5010-5014_Multipurpose
TP5, TP6, TP8, TP9, TP10, TP11, TP12, TP13, TP15, TP16: TestPoint; TestPoint_Keystone_5000-5004_Miniature
U1: LTC3531; TSOT-23-6
U4, U6: TMCS1101A3UQDT; TMCS1101
U5: TPS61030PWP; PWP0016K_L
U7: STM32G431KBT6; LQFP-32
U8: ECS-TXO-2520MV-320-AN-TR; SMD04_XTAL_2P5X2_ECS
U13: VOM1271T; SOP-4_VIS-L

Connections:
/3V3: C1.1, C11.1, C31.1, C32.1, C33.1, C34.1, C35.1, D5.2 (A), TP6.1, U1.3 (VOUT), U4.8 (VS), U6.8 (VS), U7.1 (VDD), U7.15 (VDDA), U7.17 (VDD), U8.1 (TRI), U8.4 (VDD); also elsewhere on the board
/5V: C7.2, C9.1, C10.1, J3.1, J5.1, J6.3, R7.2, TP5.1, U5.13 (VOUT), U5.14 (VOUT), U5.15 (VOUT), U13.1; also elsewhere on the board
/Aux_Batt+: J2.1, SW1.1
/Aux_In_Safe: F2.1, U6.1 (IN+), U6.2 (IN+)
/Aux_Out_Safe: C2.1, C6.2, C8.2, C17.2, L2.1, R11.1, U1.4 (*SHDN), U1.5 (VIN), U5.6 (VBAT), U5.8 (SYNC), U5.9 (EN), U6.3 (IN), U6.4 (IN)
/CLK_32: U7.2 (PF0-OSC_IN), U8.3 (OUT)
/MCU_Aux_CurrentSense: U6.7 (VOUT), U7.9 (PA4)
/MCU_Aux_VoltageSense: R11.2, R12.1, U7.10 (PA5)
/MCU_GateDrive_Disable: U7.21 (PA11); also elsewhere on the board
/MCU_LED1: D3.2 (A), U7.20 (PA10)
/MCU_LED2: D4.2 (A), U7.19 (PA9)
/MCU_Main_CurrentSense: U4.7 (VOUT), U7.11 (PA6)
/MCU_Main_Enable: R23.1, U7.12 (PA7)
/MCU_Main_VoltageSense: R9.2, R10.1, U7.13 (PB0)
/MCU_NRST: C14.2, R19.2, SW2.1, U7.4 (PG10-NRST)
/MCU_Output_VoltageSense: J7.1, R21.1, TP8.1, U7.6 (PA1)
/MCU_PWM: TP16.1, U7.25 (PA15); also elsewhere on the board
/MCU_PWM_N: TP13.1, U7.26 (PB3); also elsewhere on the board
/MCU_PressTran_VoltageSense: R27.2, R28.1, U7.5 (PA0)
/MCU_RX_from_FCU: J3.2, TP10.1, U7.30 (PB7)
/MCU_SWCLK: J4.06, U7.24 (PA14)
/MCU_SWDIO: J4.04, U7.23 (PA13)
/MCU_TX_to_FCU: J3.3, TP15.1, U7.29 (PB6)
/MCU_VCP_RX: J4.13, U7.8 (PA3)
/MCU_VCP_TX: J4.14, U7.7 (PA2)
/Main_Batt+: F1.2, J1.1
/Main_Cutoff_Gate: Q5.1 (G), R18.1, U13.4
/Main_Fused: F1.1, Q5.2 (D)
/Main_In_Safe: C12.2, Q5.3 (S), U4.1 (IN+), U4.2 (IN+), U13.3
/Main_Out_Safe: C15.2, C18.2, C19.2, C20.2, C21.2, C23.1, C24.1, C25.1, R9.1, TP12.1, U4.3 (IN), U4.4 (IN); also elsewhere on the board
/SW3: TP1.1, TP11.1; also elsewhere on the board
/SW4: TP2.1, TP9.1; also elsewhere on the board
/Transducer_Signal: J6.1, R27.1
GND: C1.2, C2.2, C6.1, C8.1, C9.2, C10.2, C11.2, C14.1, C15.1, C17.1, C18.1, C19.1, C20.1, C21.1, C23.2, C24.2, C25.2, C31.2, C32.2, C33.2, C34.2, C35.2, J1.2, J2.2, J3.6, J4.05, J4.07, J5.2, J6.2, J7.2, Q7.2 (S), R8.1, R10.2, R12.2, R15.2, R16.2, R17.2, R21.2, R28.2, SW1.3, SW2.3, TP4.1, TP14.1, U1.2 (GND/PGND), U4.5 (GND), U5.3 (PGND), U5.4 (PGND), U5.5 (PGND), U5.7 (LBI), U5.10 (LBO), U5.11 (GND), U5.17 (PAD), U6.5 (GND), U7.14 (VSSA), U7.16 (VSS), U7.32 (VSS), U8.2 (GND); also elsewhere on the board
unnamed: C12.1, R18.2
unnamed: D3.1 (K), R15.1
unnamed: D4.1 (K), R16.1
unnamed: D5.1 (K), R17.1
unnamed: F2.2, SW1.2
unnamed: J4.12, R19.1
unnamed: L2.2, U5.1 (SW), U5.2 (SW)
unnamed: Q7.3 (D), R22.2
unnamed: Q7.1 (G), R23.2
unnamed: R22.1, U13.2
unnamed: L1.2, U1.6 (SW1)
unnamed: L1.1, U1.1 (SW2)
unnamed: C7.1, R7.1, R8.2, U5.12 (FB)

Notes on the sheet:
5V 2A supply
Indication
1S to 3.3V buck-boost
Gate Drive
Cutoff switch + fuse
Analog Sense
Main bypass cap

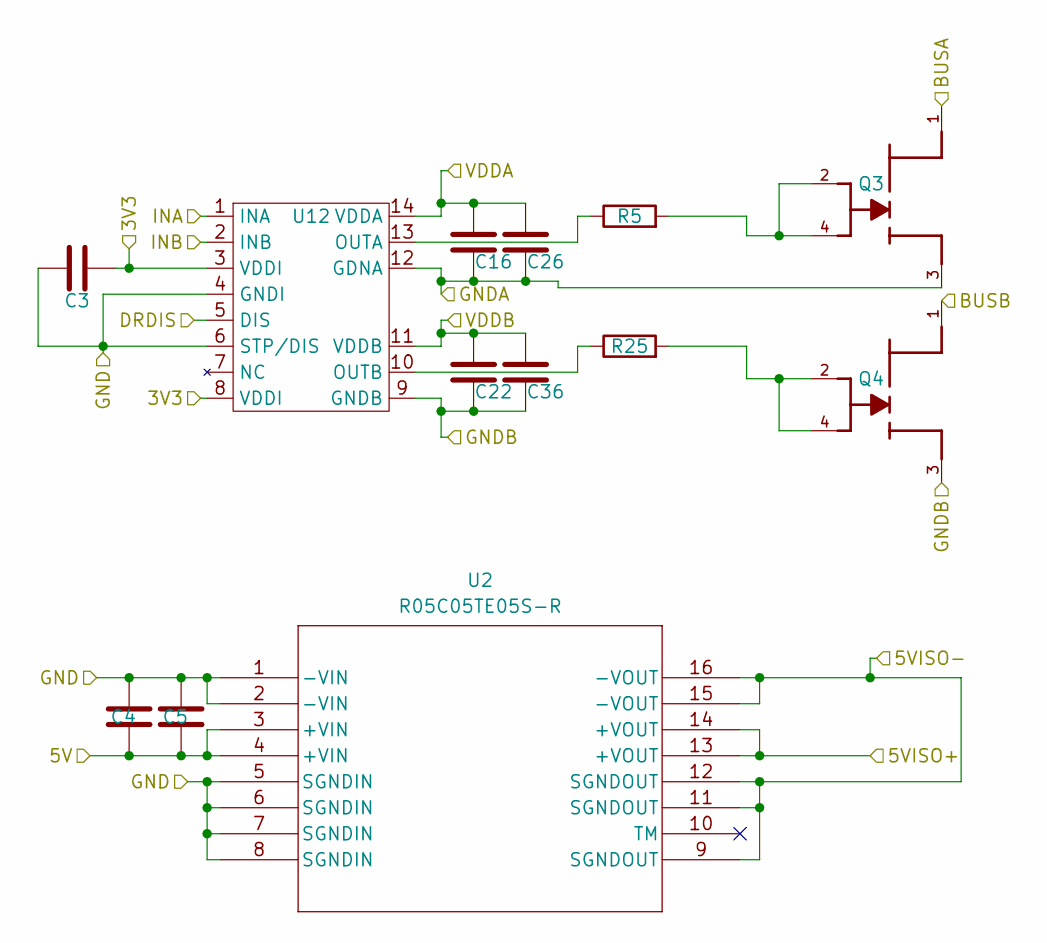
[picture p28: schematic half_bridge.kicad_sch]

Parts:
C3, C5: CGA3E1X7R1E105K080AC; C_0603_1608Metric
C4: CL21B106KOQNNNG; C_0805_2012Metric
C16, C22: C0805X473J3GECAUTO; C_0805_2012Metric
C26, C36: GRM31C5C1E474JE01L; C_1206_3216Metric
Q3, Q4: GS66516T-MR; TRANS_GS66516T-MR; PARTREV Rev 210727
R5, R25: CRCW06034R70FKEAHP; R_0603_1608Metric
U2: R05C05TE05S-R; SMD_16_10.35X7.5X2.5_RCP
U12: 2EDR7259X

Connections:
/3V3: C3.2, U12.3 (VDDI), U12.8 (VDDI); also elsewhere on the board
/5V: C4.2, C5.2, C22.1, C36.1, U2.3 (+VIN), U2.4 (+VIN), U12.11 (VDDB); also elsewhere on the board
/MCU_GateDrive_Disable: U12.5 (DIS); also elsewhere on the board
/MCU_PWM: U12.2 (INB); also elsewhere on the board
/MCU_PWM_N: U12.1 (INA); also elsewhere on the board
/Main_Out_Safe: Q3.1; also elsewhere on the board
/SW4: C16.2, C26.2, Q3.3, Q4.1, U2.9 (SGNDOUT), U2.11 (SGNDOUT), U2.12 (SGNDOUT), U2.15 (-VOUT), U2.16 (-VOUT), U12.12 (GDNA); also elsewhere on the board
/half_bridge4/5VISO+: C16.1, C26.1, U2.13 (+VOUT), U2.14 (+VOUT), U12.14 (VDDA)
GND: C3.1, C4.1, C5.1, C22.2, C36.2, Q4.3, U2.1 (-VIN), U2.2 (-VIN), U2.5 (SGNDIN), U2.6 (SGNDIN), U2.7 (SGNDIN), U2.8 (SGNDIN), U12.4 (GNDI), U12.6 (STP/DIS), U12.9 (GNDB); also elsewhere on the board
unnamed: Q3.2, Q3.4, R5.2
unnamed: Q4.2, Q4.4, R25.2
unnamed: R5.1, U12.13 (OUTA)
unnamed: R25.1, U12.10 (OUTB)

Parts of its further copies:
C27, C29: CGA3E1X7R1E105K080AC; C_0603_1608Metric
C28: CL21B106KOQNNNG; C_0805_2012Metric
C30, C40: C0805X473J3GECAUTO; C_0805_2012Metric
C43, C44: GRM31C5C1E474JE01L; C_1206_3216Metric
Q1, Q2: GS66516T-MR; TRANS_GS66516T-MR; PARTREV Rev 210727
R1, R3: CRCW06034R70FKEAHP; R_0603_1608Metric
U3: R05C05TE05S-R; SMD_16_10.35X7.5X2.5_RCP
U11: 2EDR7259X

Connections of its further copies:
/3V3: C27.2, U11.3 (VDDI), U11.8 (VDDI); also elsewhere on the board
/5V: C28.2, C29.2, C30.1, C43.1, U3.3 (+VIN), U3.4 (+VIN), U11.14 (VDDA); also elsewhere on the board
/MCU_GateDrive_Disable: U11.5 (DIS); also elsewhere on the board
/MCU_PWM: U11.2 (INB); also elsewhere on the board
/MCU_PWM_N: U11.1 (INA); also elsewhere on the board
/Main_Out_Safe: Q1.1; also elsewhere on the board
/SW3: C40.2, C44.2, Q1.3, Q2.1, U3.9 (SGNDOUT), U3.11 (SGNDOUT), U3.12 (SGNDOUT), U3.15 (-VOUT), U3.16 (-VOUT), U11.9 (GNDB); also elsewhere on the board
/half_bridge3/5VISO+: C40.1, C44.1, U3.13 (+VOUT), U3.14 (+VOUT), U11.11 (VDDB)
GND: C27.1, C28.1, C29.1, C30.2, C43.2, Q2.3, U3.1 (-VIN), U3.2 (-VIN), U3.5 (SGNDIN), U3.6 (SGNDIN), U3.7 (SGNDIN), U3.8 (SGNDIN), U11.4 (GNDI), U11.6 (STP/DIS), U11.12 (GDNA); also elsewhere on the board
unnamed: Q1.2, Q1.4, R3.2
unnamed: Q2.2, Q2.4, R1.2
unnamed: R1.1, U11.13 (OUTA)
unnamed: R3.1, U11.10 (OUTB)

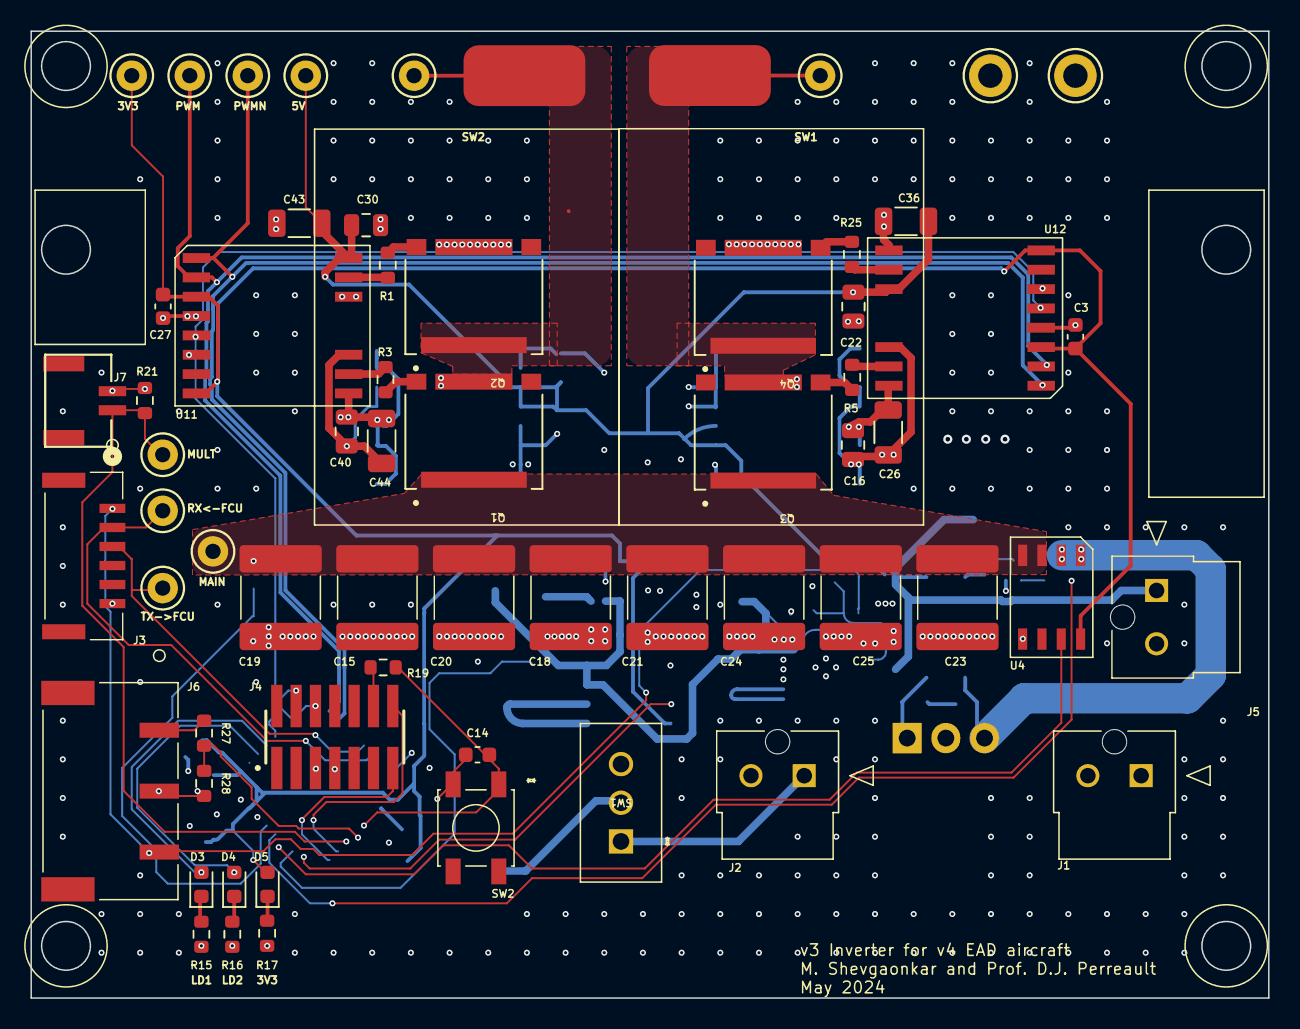
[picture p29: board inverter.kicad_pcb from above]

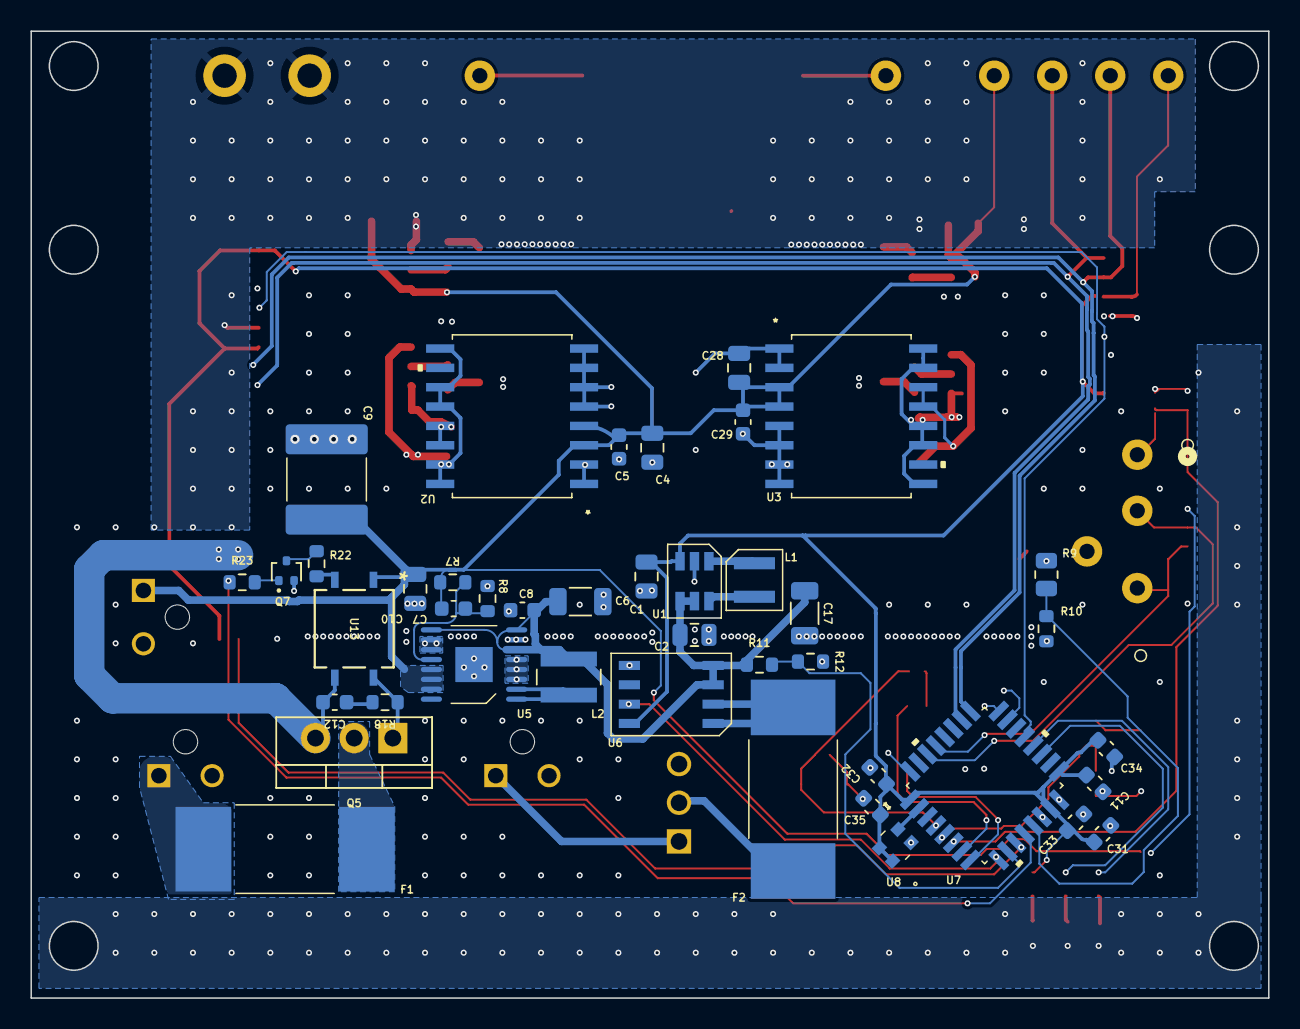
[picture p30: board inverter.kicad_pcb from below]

Board: 4 copper layers, 81.3 x 63.5 mm, 105 parts (42 on the bottom side), 57 nets.

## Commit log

2025-12-01 add optimization routines, pcbs, readme
    [CON10_2X5_DUK_FTSH_SAI.step, FTSH-107-01-L-DV-K-A.step, GS66508B-MR.step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]
2025-12-01 add simulation and cad files
    [CON10_2X5_DUK_FTSH_SAI.step, ETD59-integrated-base-raised-nov21.SLDPRT, ETD59-integrated-bottom-raised-0.8mm-dec9.SLDPRT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]

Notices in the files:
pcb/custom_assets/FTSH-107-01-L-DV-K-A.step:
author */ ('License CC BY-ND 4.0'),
